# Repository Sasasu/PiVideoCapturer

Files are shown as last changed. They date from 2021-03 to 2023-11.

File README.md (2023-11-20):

# PiVideoCapturer

A video capturer using TC358840XBG and arm SoC



Linux driver for [Linux 4.x](https://patchwork.kernel.org/project/linux-media/patch/44d2d84d-f18d-9c80-977f-8a2b8675e70a@xs4all.nl/) and [Linux 5.x](https://github.com/Sasasu/kernel/commit/2ac963e2eb28087317501f061d04d1e15ed70adb)

Also a [DTS example](https://github.com/Sasasu/kernel/commit/191d50bea6500b790de900fb8ab7bc9170189c27).

And a [debugging driver](https://github.com/Sasasu/kernel/blob/nanopi4-linux-v4.4.y/drivers/media/i2c/tc358840.c) for RK3399 with kernel 4.4.

License: GPLv3

----

TC358840XBG is completely EOL now. I personally recommend use RK3588 instead, RK3588 has a HDMI IN port.

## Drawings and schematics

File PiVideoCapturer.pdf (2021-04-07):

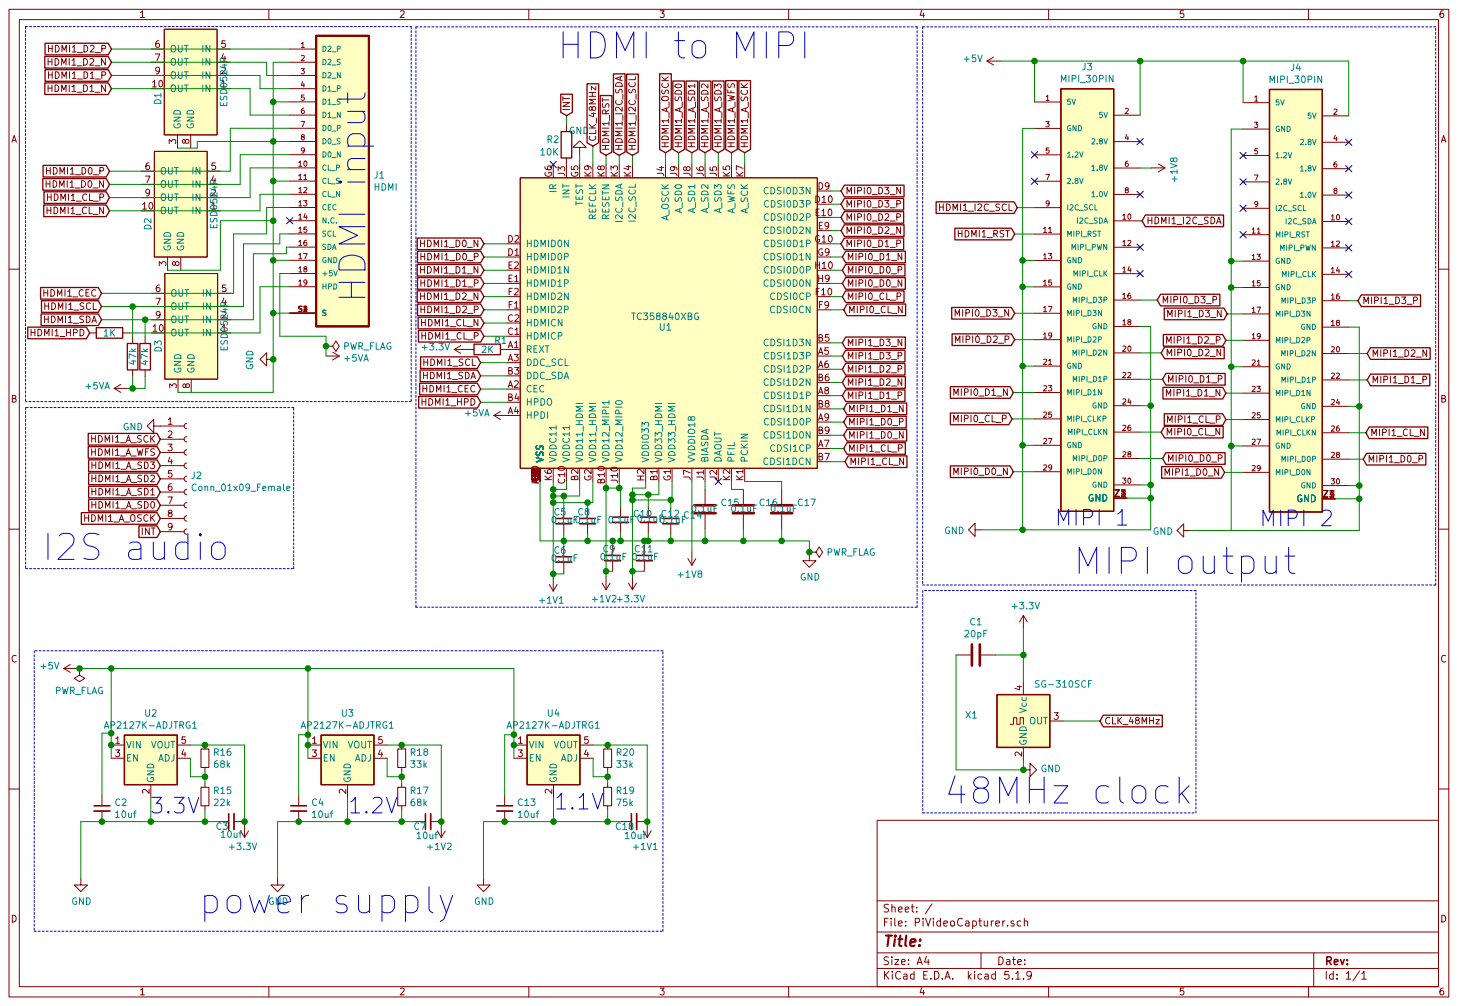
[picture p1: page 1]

OUT 7 GND IN | 5 OUT 6

IN IN | 2 GND 1 OUT 10

2 OUT 3 Vcc 4 X1 SG-310SCF GND GND 1

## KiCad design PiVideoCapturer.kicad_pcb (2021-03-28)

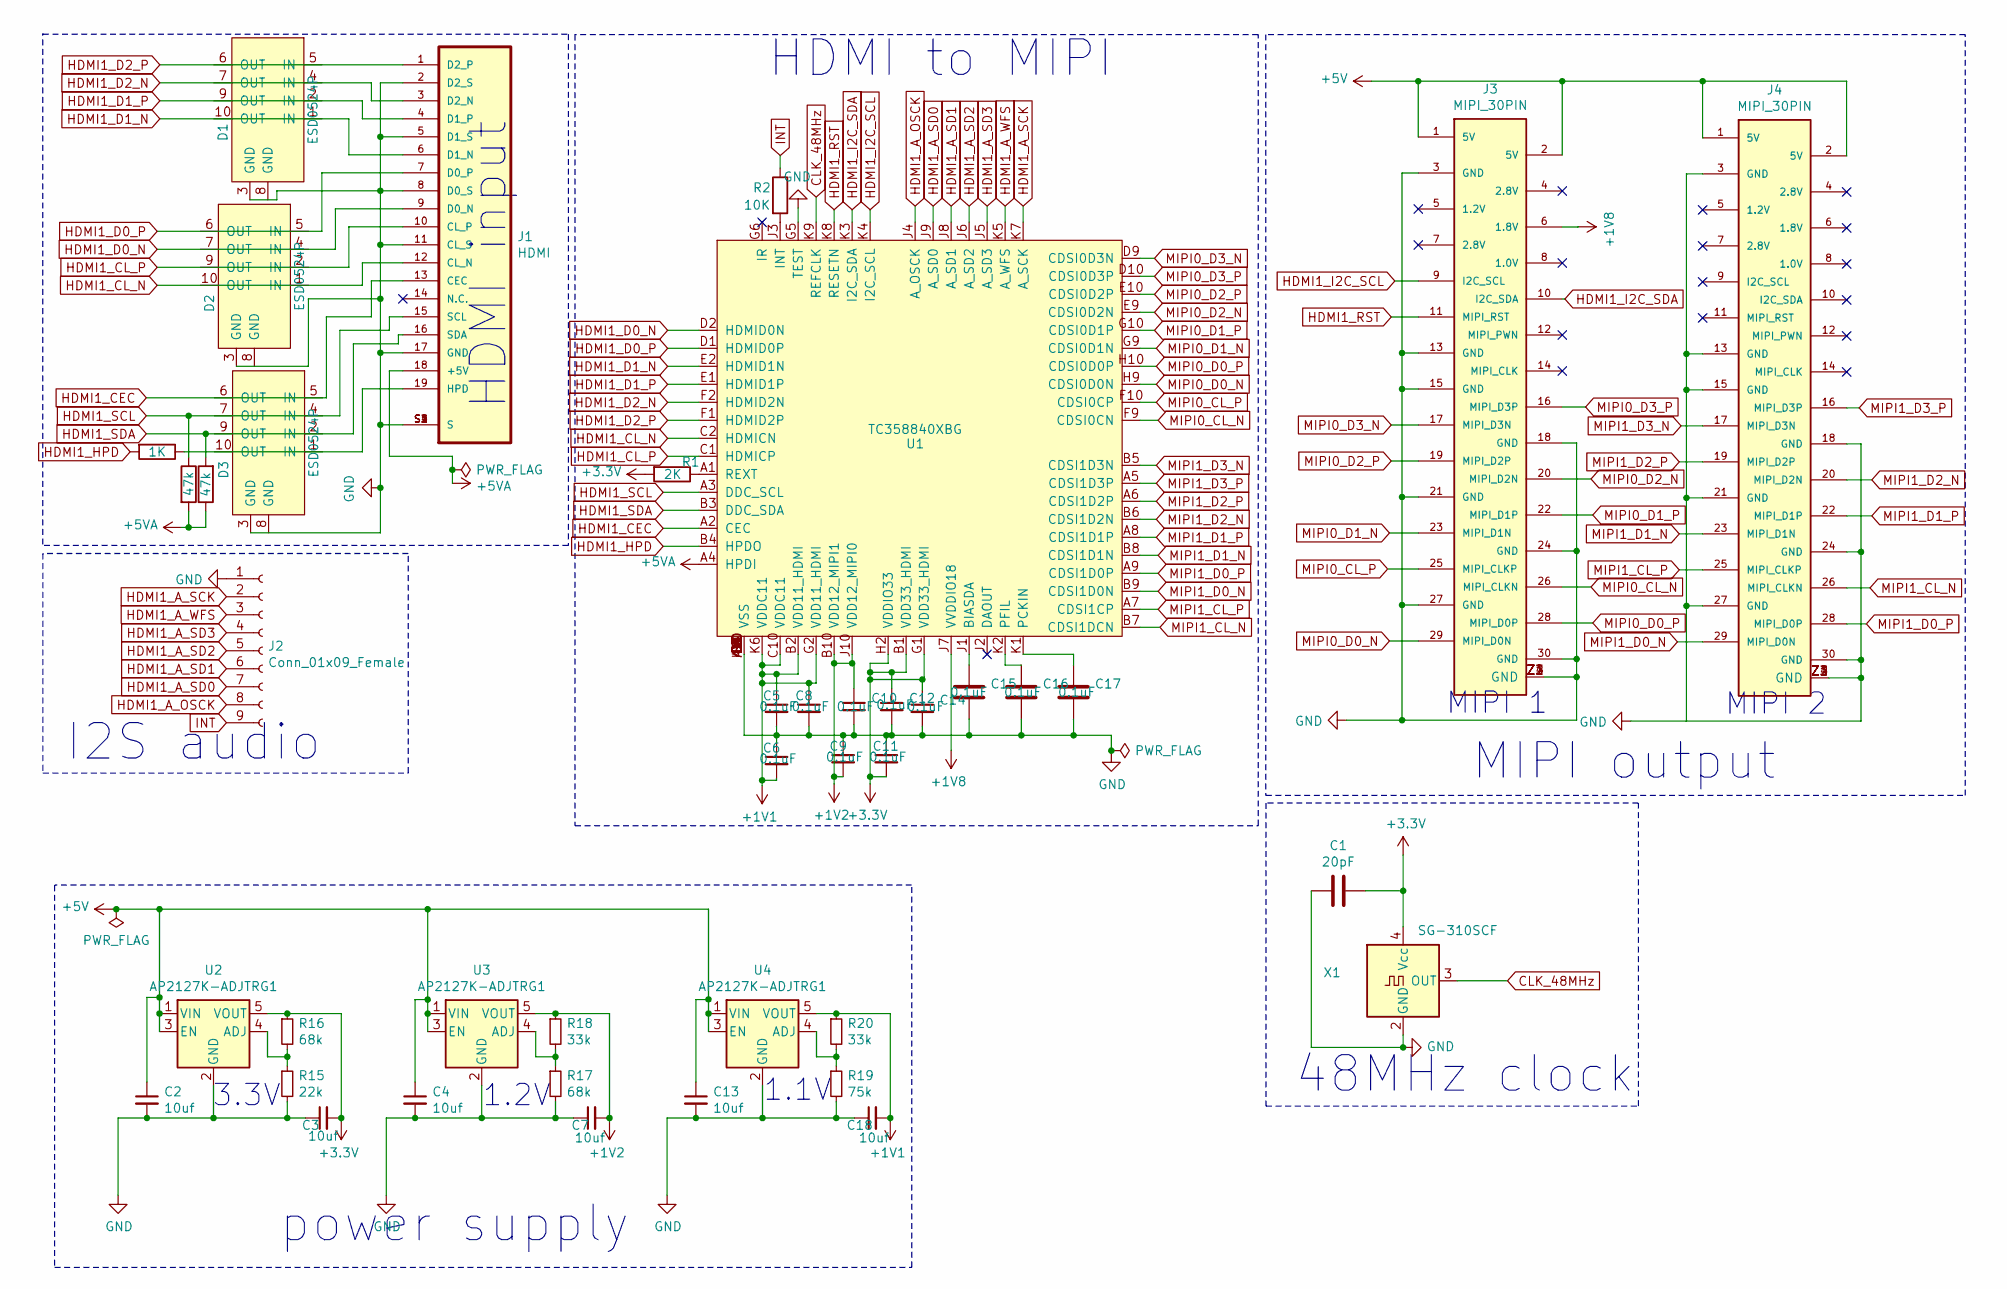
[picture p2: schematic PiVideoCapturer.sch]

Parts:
C1: 20pF; C_0402_1005Metric
C2, C3, C4, C7, C13, C18: 10uf; C_0402_1005Metric
C5, C6, C8, C9, C10, C11, C12, C14, C15, C16, C17: 0.1uF; C_0402_1005Metric
D1, D2, D3: ESD0524P; Diodes_UDFN-10_1.0x2.5mm_P0.5mm
J1: HDMI; TE_5-1903015-5
J2: Conn_01x09_Female; PinSocket_1x09_P2.54mm_Vertical
J3, J4: MIPI_30PIN; MIPI_30PIN_FPC_0.5mm
R1: 2K; R_0402_1005Metric
R2: 10K; R_0402_1005Metric
R10, R12: 47k; R_0402_1005Metric
R11: 1K; R_0402_1005Metric
R15: 22k; R_0402_1005Metric
R16, R17: 68k; R_0402_1005Metric
R18, R20: 33k; R_0402_1005Metric
R19: 75k; R_0402_1005Metric
U1: TC358840XBG; BGA80C65P10X10_700X700X100N
U2, U3, U4: AP2127K-ADJTRG1; SOT-23-5
X1: SG-310SCF; Crystal_SMD_3225-4Pin_3.2x2.5mm

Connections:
+1V1: C5.1, C6.2, C8.1, C18.2, R20.1, U1.B2 (VDD11_HDMI), U1.C10 (VDDC11), U1.G2 (VDD11_HDMI), U1.K6 (VDDC11), U4.5 (VOUT)
+1V2: C7.2, C9.2, C10.1, R18.1, U1.B10 (VDD12_MIPI1), U1.J10 (VDD12_MIPI0), U3.5 (VOUT)
+1V8: J3.6 (1.8V), U1.J7 (VVDDIO18)
+3V3: C1.1, C3.2, C11.2, C12.1, C14.1, R1.2, R16.1, U1.B1 (VDD33_HDMI), U1.G1 (VDD33_HDMI), U1.H2 (VDDIO33), U2.5 (VOUT), X1.4 (Vcc)
+5V: C2.1, C4.1, C13.1, J3.1 (5V), J3.2 (5V), J4.1 (5V), J4.2 (5V), U2.1 (VIN), U2.3 (EN), U3.1 (VIN), U3.3 (EN), U4.1 (VIN), U4.3 (EN)
+5VA: J1.18 (+5V), R10.2, R12.1, U1.A4 (HPDI)
CLK_48MHz: U1.K9 (REFCLK), X1.3 (OUT)
GND: C1.2, C2.2, C3.1, C4.2, C5.2, C6.1, C7.1, C8.2, C9.1, C10.2, C11.1, C12.2, C13.2, C14.2, C15.1, C16.1, C17.1, C18.1, D1.3 (GND), D2.3 (GND), D3.3 (GND), J1.2 (D2_S), J1.5 (D1_S), J1.8 (D0_S), J1.11 (CL_S), J1.17 (GND), J1.S1 (S), J1.S2 (S), J1.S3 (S), J1.S4 (S), J2.1, J3.3 (GND), J3.13 (GND), J3.15 (GND), J3.18 (GND), J3.21 (GND), J3.24 (GND), J3.27 (GND), J3.30 (GND), J3.Z1 (GND), J3.Z2 (GND), J3.Z3 (GND), J3.Z4 (GND), J4.3 (GND), J4.13 (GND), J4.15 (GND), J4.18 (GND), J4.21 (GND), J4.24 (GND), J4.27 (GND), J4.30 (GND), J4.Z1 (GND), J4.Z2 (GND), J4.Z3 (GND), J4.Z4 (GND), R15.2, R17.2, R19.2, U1.A10 (VSS), U1.C9 (VSS), U1.D4 (VSS), U1.D5 (VSS), U1.D6 (VSS), U1.D7 (VSS), U1.E4 (VSS), U1.E5 (VSS), U1.E6 (VSS), U1.E7 (VSS), U1.F4 (VSS), U1.F5 (VSS), U1.F6 (VSS), U1.F7 (VSS), U1.G4 (VSS), U1.G5 (TEST), U1.G7 (VSS), U1.H1 (VSS), U1.K10 (VSS), U2.2 (GND), U3.2 (GND), U4.2 (GND), X1.2 (GND)
HDMI1_A_OSCK: J2.8, U1.J4 (A_OSCK)
HDMI1_A_SCK: J2.2, U1.K7 (A_SCK)
HDMI1_A_SD0: J2.7, U1.J9 (A_SD0)
HDMI1_A_SD1: J2.6, U1.J8 (A_SD1)
HDMI1_A_SD2: J2.5, U1.J6 (A_SD2)
HDMI1_A_SD3: J2.4, U1.J5 (A_SD3)
HDMI1_A_WFS: J2.3, U1.K5 (A_WFS)
HDMI1_CEC: J1.13 (CEC), U1.A2 (CEC)
HDMI1_CL_N: J1.12 (CL_N), U1.C2 (HDMICN)
HDMI1_CL_P: J1.10 (CL_P), U1.C1 (HDMICP)
HDMI1_D0_N: J1.9 (D0_N), U1.D2 (HDMID0N)
HDMI1_D0_P: J1.7 (D0_P), U1.D1 (HDMID0P)
HDMI1_D1_N: J1.6 (D1_N), U1.E2 (HDMID1N)
HDMI1_D1_P: J1.4 (D1_P), U1.E1 (HDMID1P)
HDMI1_D2_N: J1.3 (D2_N), U1.F2 (HDMID2N)
HDMI1_D2_P: J1.1 (D2_P), U1.F1 (HDMID2P)
HDMI1_HPD: R11.2, U1.B4 (HPDO)
HDMI1_I2C_SCL: J3.9 (I2C_SCL), U1.K4 (I2C_SCL)
HDMI1_I2C_SDA: J3.10 (I2C_SDA), U1.K3 (I2C_SDA)
HDMI1_RST: J3.11 (MIPI_RST), U1.K8 (RESETN)
HDMI1_SCL: J1.15 (SCL), R10.1, U1.A3 (DDC_SCL)
HDMI1_SDA: J1.16 (SDA), R12.2, U1.B3 (DDC_SDA)
INT: J2.9, R2.1
MIPI0_CL_N: J3.26 (MIPI_CLKN), U1.F9 (CDSI0CN)
MIPI0_CL_P: J3.25 (MIPI_CLKP), U1.F10 (CDSI0CP)
MIPI0_D0_N: J3.29 (MIPI_D0N), U1.H9 (CDSI0D0N)
MIPI0_D0_P: J3.28 (MIPI_D0P), U1.H10 (CDSI0D0P)
MIPI0_D1_N: J3.23 (MIPI_D1N), U1.G9 (CDSI0D1N)
MIPI0_D1_P: J3.22 (MIPI_D1P), U1.G10 (CDSI0D1P)
MIPI0_D2_N: J3.20 (MIPI_D2N), U1.E9 (CDSI0D2N)
MIPI0_D2_P: J3.19 (MIPI_D2P), U1.E10 (CDSI0D2P)
MIPI0_D3_N: J3.17 (MIPI_D3N), U1.D9 (CDSI0D3N)
MIPI0_D3_P: J3.16 (MIPI_D3P), U1.D10 (CDSI0D3P)
MIPI1_CL_N: J4.26 (MIPI_CLKN), U1.B7 (CDSI1DCN)
MIPI1_CL_P: J4.25 (MIPI_CLKP), U1.A7 (CDSI1CP)
MIPI1_D0_N: J4.29 (MIPI_D0N), U1.B9 (CDSI1D0N)
MIPI1_D0_P: J4.28 (MIPI_D0P), U1.A9 (CDSI1D0P)
MIPI1_D1_N: J4.23 (MIPI_D1N), U1.B8 (CDSI1D1N)
MIPI1_D1_P: J4.22 (MIPI_D1P), U1.A8 (CDSI1D1P)
MIPI1_D2_N: J4.20 (MIPI_D2N), U1.B6 (CDSI1D2N)
MIPI1_D2_P: J4.19 (MIPI_D2P), U1.A6 (CDSI1D2P)
MIPI1_D3_N: J4.17 (MIPI_D3N), U1.B5 (CDSI1D3N)
MIPI1_D3_P: J4.16 (MIPI_D3P), U1.A5 (CDSI1D3P)
unnamed: C15.2, U1.J1 (BIASDA)
unnamed: C16.2, U1.K2 (PFIL)
unnamed: C17.2, U1.K1 (PCKIN)
unnamed: J1.19 (HPD), R11.1
unnamed: R1.1, U1.A1 (REXT)
unnamed: R2.2, U1.J3 (INT)
unnamed: R15.1, R16.2, U2.4 (ADJ)
unnamed: R17.1, R18.2, U3.4 (ADJ)
unnamed: R19.1, R20.2, U4.4 (ADJ)

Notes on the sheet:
HDMI input
48MHz clock
I2S audio
MIPI 2
MIPI output
HDMI to MIPI
power supply
3.3V
1.2V
1.1V
MIPI 1

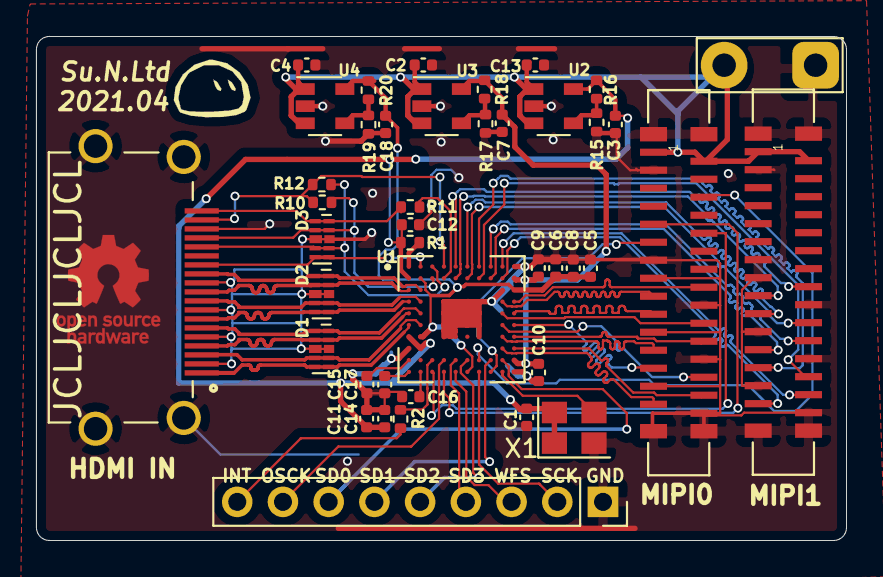
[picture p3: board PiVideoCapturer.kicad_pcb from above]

Board: 2 copper layers, 45.0 x 28.0 mm, 41 parts (0 on the bottom side), 60 nets.

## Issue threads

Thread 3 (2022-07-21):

LCD compatibility list?

manrand, 2022-07-21:
Hi @Sasasu

Well done! 👍

Would this project compare with https://hackaday.io/project/364/logs which allowed to convert HDMI to MIPI in order to reuse smartphone (iPhone) screens ?

If so, which LCDs are know to work?

🙏

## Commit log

2021-03-29 BOM: add FPC 30P 0.5mm vertical
    [PiVideoCapturer.sch]
2021-03-31 bom: add TC358840XBG part number
    [PiVideoCapturer.sch]
2021-04-05 Add debug driver
